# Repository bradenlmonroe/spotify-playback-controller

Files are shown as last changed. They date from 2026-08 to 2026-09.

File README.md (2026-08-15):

The overall goal of the project was to create a better way to control my Spotify listening experience.

Music plays a large part in my life, and I rely on having music in the background to get work done.  However, many of the applications I use on the desktop have the same issue - if i want to interact with the app in any way,  to skip the current song, to look at the artist, to even pause it, requires tabbing through all of my screens and getting lost in pages.  If I leave the window open, I lose valuable monitor real estate.

I then set out to find a solution that would allow me to control my music without dedicating a whole monitor to the application.  Although other solutions exist, including modding a depreciated Spotify Car Thing, I concluded that these solutions were outside the scope of what I wanted the project to accomplish.

After going back and forth between a few options, I settled on using an ESP32 as the microcontroller.  I didn't need anything as powerful as a Raspberry Pi 4 or the STM32, and the ESP offered easily plug-and-play operation with the already-required type-C cable connection.

The rotary encoder was a leftover piece from another project, and has added integrations including the push-button capability and the LED embedded in the handle.

The monitor was selected for its size and cost. Additionally, it boasted not supporting touchscreen, which is a benefit for this project due to the rotary encoder being the main source of control.

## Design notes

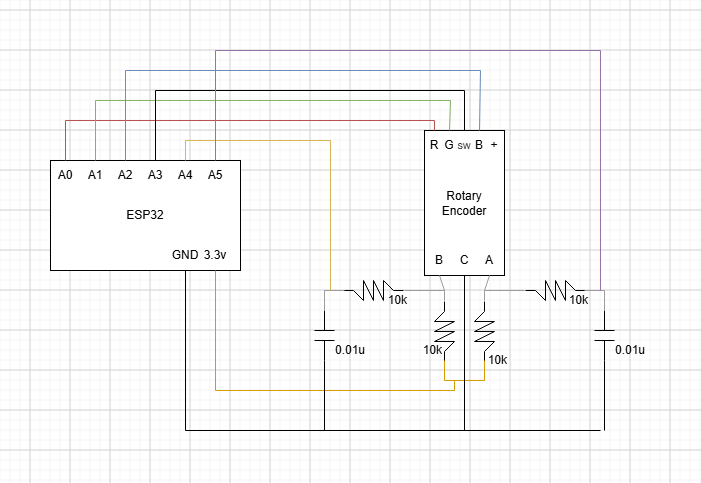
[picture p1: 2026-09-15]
Documentation/spotify desk thing (rotary encoder)-electrical diagram.drawio.png

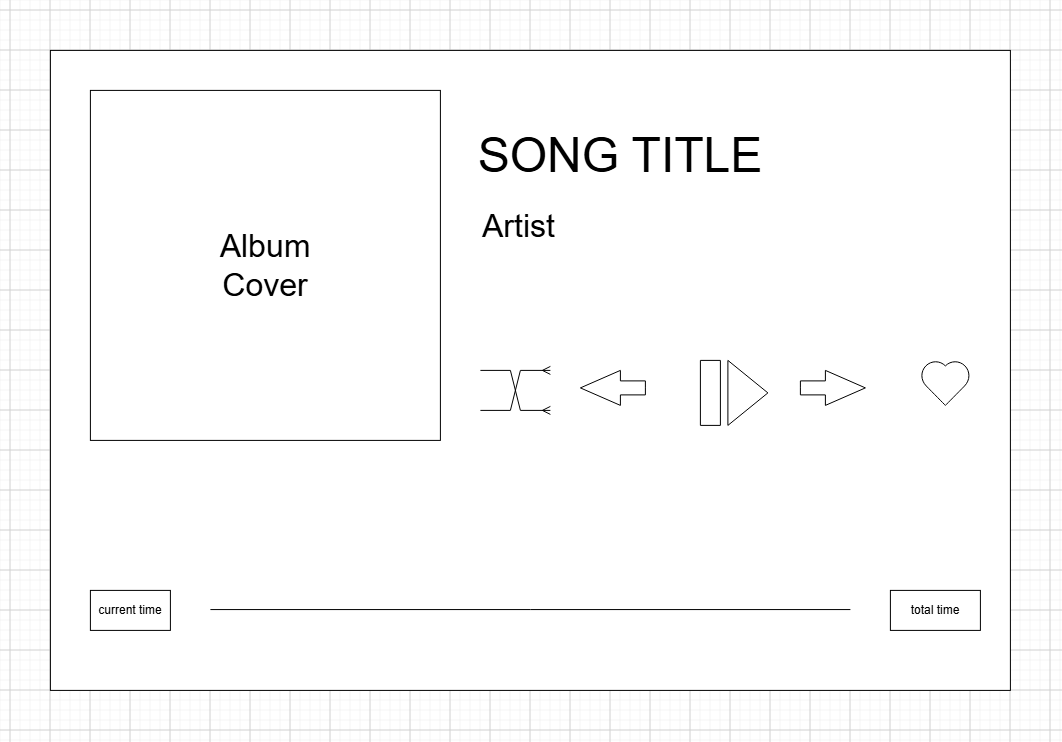
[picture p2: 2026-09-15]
Documentation/spotify desk thing (rotary encoder)-UI.drawio.png

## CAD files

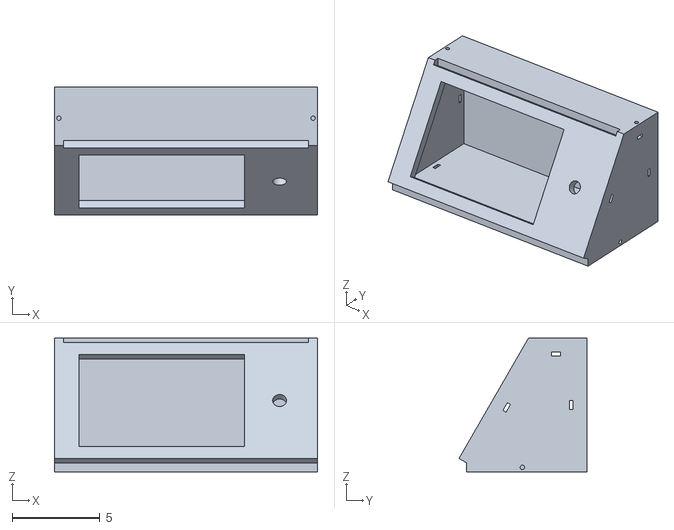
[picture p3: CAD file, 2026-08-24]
hardware/cad/case assembly (1).stl
15.0 x 7.30 x 7.62

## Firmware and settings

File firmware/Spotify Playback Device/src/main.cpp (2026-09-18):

#include <Arduino.h>
#include <SPI.h>
#include <Arduino_GFX_Library.h>
#include <WiFi.h>
#include <WiFiClientSecure.h>
#include <HTTPClient.h>
#include <ArduinoJson.h>
#include <JPEGDEC.h>
#include "esp_heap_caps.h"
#include "secrets.h"

// Known-good wiring from screen_tester.cpp
#define TFT_CS    4
#define TFT_RST   5
#define TFT_DC    6
#define TFT_MOSI  7
#define TFT_SCK   8

// Rotary encoder wiring
#define ENCODER_A    16
#define ENCODER_B    17
#define ENCODER_PUSH 39

Arduino_DataBus *bus =
    new Arduino_HWSPI(TFT_DC, TFT_CS);

Arduino_GFX *gfx =
    new Arduino_ST7796(
        bus,
        TFT_RST,
        1,      // landscape
        false
    );

// ---------- Playback state ----------

struct PlaybackState {
    String title;
    String artist;
    uint32_t durationMs;
    uint32_t progressMs;
    bool playing;
    bool shuffle;
    bool liked;
    String uri;
    String albumArtUrl;
};

PlaybackState playback = {
    "SONG TITLE",
    "Artist",
    222000,     // 3:42
    84000,      // 1:24
    true,
    false,
    false,
    "",
    ""
};

uint32_t positionReceivedAt = 0;

// ---------- Spotify / network state ----------

String spotifyAccessToken;
uint32_t spotifyTokenExpiresAt = 0;
uint32_t lastSpotifyPoll = 0;
uint32_t spotifyRefreshRequestedAt = 0;

constexpr uint32_t SPOTIFY_POLL_INTERVAL = 2000;
constexpr uint32_t SPOTIFY_COMMAND_REFRESH_DELAY = 350;

bool albumArtNeedsUpdate = false;
volatile bool albumArtTaskRunning = false;

constexpr size_t ALBUM_URL_SIZE = 256;
char pendingAlbumArtUrl[ALBUM_URL_SIZE] = "";


// ---------- 480 x 320 layout ----------

constexpr int ALBUM_X = 20;
constexpr int ALBUM_Y = 25;
constexpr int ALBUM_SIZE = 190;

constexpr int INFO_X = 230;

constexpr int BAR_X = 65;
constexpr int BAR_Y = 285;
constexpr int BAR_W = 350;
constexpr int BAR_H = 4;

// ---------- Encoder / control selection ----------

enum ControlIndex {
    CONTROL_SHUFFLE = 0,
    CONTROL_PREVIOUS,
    CONTROL_PLAY_PAUSE,
    CONTROL_NEXT,
    CONTROL_LIKE,
    CONTROL_COUNT
};

int selectedControl = CONTROL_PLAY_PAUSE;

// Set this to -1 if the knob moves opposite the direction you expect.
constexpr int ENCODER_DIRECTION = 1;

int8_t encoderAccumulator = 0;
uint8_t previousEncoderState = 0;

// The SparkFun encoder button is unusual: SW idles LOW and goes HIGH
// when pressed, so use INPUT_PULLDOWN + a RISING-edge interrupt.
volatile bool buttonFlagPressed = false;
volatile uint32_t lastButtonISRTime = 0;
constexpr uint32_t BUTTON_DEBOUNCE_MS = 30;

void IRAM_ATTR buttonISR()
{
    uint32_t now = millis();

    if (now - lastButtonISRTime > BUTTON_DEBOUNCE_MS) {
        buttonFlagPressed = true;
        lastButtonISRTime = now;
    }
}

void drawAlbumPlaceholder();
void drawSongInfo();
void drawControls();
void resetProgressBar();
bool downloadAndDrawAlbumArt(const String &url);
void updateAlbumArt();
void albumArtTask(void *parameter);

// ---------- WiFi / Spotify ----------

void connectWiFi()
{
    Serial.print("Connecting to WiFi");

    WiFi.mode(WIFI_STA);
    WiFi.begin(WIFI_SSID, WIFI_PASSWORD);

    while (WiFi.status() != WL_CONNECTED) {
        delay(500);
        Serial.print(".");
    }

    Serial.println();
    Serial.println("WiFi connected");
    Serial.print("IP: ");
    Serial.println(WiFi.localIP());
}

bool refreshSpotifyToken()
{
    WiFiClientSecure client;
    client.setInsecure(); // Bring-up only; use certificate validation for production.

    HTTPClient http;

    if (!http.begin(client, "https://accounts.spotify.com/api/token")) {
        Serial.println("Could not connect to Spotify accounts");
        return false;
    }

    http.addHeader("Content-Type", "application/x-www-form-urlencoded");

    String body =
        "grant_type=refresh_token"
        "&refresh_token=" + String(SPOTIFY_REFRESH_TOKEN) +
        "&client_id=" + String(SPOTIFY_CLIENT_ID);

    int status = http.POST(body);
    String response = http.getString();

    if (status != 200) {
        Serial.printf("Token refresh failed: HTTP %d\n", status);
        Serial.println(response);
        http.end();
        return false;
    }

    JsonDocument doc;
    DeserializationError error = deserializeJson(doc, response);

    if (error) {
        Serial.print("Could not parse token JSON: ");
        Serial.println(error.c_str());
        http.end();
        return false;
    }

    spotifyAccessToken = doc["access_token"].as<String>();
    uint32_t expiresIn = doc["expires_in"] | 3600;

    // Refresh one minute before Spotify's reported expiration.
    spotifyTokenExpiresAt = millis() + (expiresIn > 60 ? expiresIn - 60 : expiresIn) * 1000UL;

    Serial.println("Spotify access token obtained");
    http.end();
    return !spotifyAccessToken.isEmpty();
}

String urlEncode(const String &value)
{
    String encoded;
    const char *hex = "0123456789ABCDEF";

    for (size_t i = 0; i < value.length(); ++i) {
        uint8_t c = (uint8_t)value[i];

        if ((c >= 'a' && c <= 'z') ||
            (c >= 'A' && c <= 'Z') ||
            (c >= '0' && c <= '9') ||
            c == '-' || c == '_' || c == '.' || c == '~') {
            encoded += (char)c;
        } else {
            encoded += '%';
            encoded += hex[(c >> 4) & 0x0F];
            encoded += hex[c & 0x0F];
        }
    }

    return encoded;
}

bool spotifySuccess(int status)
{
    return status >= 200 && status < 300;
}

int spotifyRequest(const char *method, const String &url, String &response,
                   const String &body = "")
{
    if (WiFi.status() != WL_CONNECTED || spotifyAccessToken.isEmpty()) {
        return -1;
    }

    WiFiClientSecure client;
    client.setInsecure();

    HTTPClient http;
    if (!http.begin(client, url)) {
        return -1;
    }

    http.addHeader("Authorization", "Bearer " + spotifyAccessToken);

    int status = -1;

    if (strcmp(method, "GET") == 0) {
        status = http.GET();
    }
    else if (strcmp(method, "POST") == 0) {
        if (body.length()) {
            http.addHeader("Content-Type", "application/json");
            status = http.POST(body);
        }
        else {
            // ESP32 HTTPClient does NOT add Content-Length when size == 0.
            // Spotify expects a body length on these bodyless POST commands.
            http.addHeader("Content-Length", "0");
            status = http.sendRequest("POST");
        }
    }
    else if (strcmp(method, "PUT") == 0) {
        if (body.length()) {
            http.addHeader("Content-Type", "application/json");
            status = http.PUT(body);
        }
        else {
            // Explicitly send Content-Length: 0 for pause/shuffle/etc.
            http.addHeader("Content-Length", "0");
            status = http.sendRequest("PUT");
        }
    }
    else if (strcmp(method, "DELETE") == 0) {
        http.addHeader("Content-Length", "0");
        status = http.sendRequest("DELETE");
    }

    // Avoid trying to drain an unknown-length/bodyless error response.
    // Playback GETs and other JSON responses normally have a positive length.
    if (status > 0 && http.getSize() > 0) {
        response = http.getString();
    }

    http.end();
    return status;
}

int spotifyRequestWithRefresh(const char *method, const String &url,
                              String &response, const String &body = "")
{
    int status = spotifyRequest(method, url, response, body);

    if (status == 401 && refreshSpotifyToken()) {
        response = "";
        status = spotifyRequest(method, url, response, body);
    }

    return status;
}

void requestSpotifyStateRefresh()
{
    spotifyRefreshRequestedAt = millis();
}

bool spotifyNext()
{
    String response;
    int status = spotifyRequestWithRefresh(
        "POST", "https://api.spotify.com/v1/me/player/next", response);

    Serial.printf("Next: HTTP %d\n", status);
    if (spotifySuccess(status)) requestSpotifyStateRefresh();
    return spotifySuccess(status);
}

bool spotifyPrevious()
{
    String response;
    int status = spotifyRequestWithRefresh(
        "POST", "https://api.spotify.com/v1/me/player/previous", response);

    Serial.printf("Previous: HTTP %d\n", status);
    if (spotifySuccess(status)) requestSpotifyStateRefresh();
    return spotifySuccess(status);
}

bool spotifyPause()
{
    String response;
    int status = spotifyRequestWithRefresh(
        "PUT", "https://api.spotify.com/v1/me/player/pause", response);

    Serial.printf("Pause: HTTP %d\n", status);
    if (spotifySuccess(status)) requestSpotifyStateRefresh();
    return spotifySuccess(status);
}

bool spotifyPlay()
{
    String response;
    int status = spotifyRequestWithRefresh(
        "PUT",
        "https://api.spotify.com/v1/me/player/play",
        response,
        "{}"
    );

    Serial.printf("Play: HTTP %d\n", status);
    if (spotifySuccess(status)) requestSpotifyStateRefresh();
    return spotifySuccess(status);
}

bool spotifySetShuffle(bool enabled)
{
    String response;
    String url = "https://api.spotify.com/v1/me/player/shuffle?state=";
    url += enabled ? "true" : "false";

    int status = spotifyRequestWithRefresh("PUT", url, response);
    Serial.printf("Shuffle: HTTP %d\n", status);

    if (spotifySuccess(status)) requestSpotifyStateRefresh();
    return spotifySuccess(status);
}

bool spotifyCheckLiked(const String &uri, bool &liked)
{
    if (uri.isEmpty()) return false;

    String response;
    String url = "https://api.spotify.com/v1/me/library/contains?uris=" +
                 urlEncode(uri);

    int status = spotifyRequestWithRefresh("GET", url, response);

    if (status != 200) {
        Serial.printf("Liked-state check: HTTP %d\n", status);
        return false;
    }

    JsonDocument doc;
    if (deserializeJson(doc, response)) {
        return false;
    }

    liked = doc[0] | false;
    return true;
}

bool spotifySetLiked(bool liked)
{
    if (playback.uri.isEmpty()) {
        Serial.println("No Spotify URI available for current item");
        return false;
    }

    String response;
    String url = "https://api.spotify.com/v1/me/library?uris=" +
                 urlEncode(playback.uri);

    int status = spotifyRequestWithRefresh(
        liked ? "PUT" : "DELETE", url, response);

    Serial.printf("%s library item: HTTP %d\n",
                  liked ? "Save" : "Remove", status);

    // Current library endpoints return HTTP 200 on success.
    if (status == 200) {
        playback.liked = liked;
        drawControls();
        requestSpotifyStateRefresh();
        return true;
    }

    return false;
}

bool getSpotifyPlayback()
{
    if (spotifyAccessToken.isEmpty()) {
        Serial.println("No Spotify access token");
        return false;
    }

    String response;
    int status = spotifyRequestWithRefresh(
        "GET", "https://api.spotify.com/v1/me/player", response);

    if (status == 204) {
        Serial.println("No active Spotify playback");
        return true;
    }

    if (status != 200) {
        Serial.printf("Playback request failed: HTTP %d\n", status);
        if (!response.isEmpty()) Serial.println(response);
        return false;
    }

    JsonDocument doc;
    DeserializationError error = deserializeJson(doc, response);

    if (error) {
        Serial.print("Could not parse playback JSON: ");
        Serial.println(error.c_str());
        return false;
    }

    JsonObject item = doc["item"].as<JsonObject>();
    if (item.isNull()) {
        Serial.println("Spotify returned no current item");
        return true;
    }

    String newTitle = item["name"].as<String>();
    String newArtist = item["artists"][0]["name"].isNull()
                           ? ""
                           : item["artists"][0]["name"].as<String>();
    String newUri = item["uri"].isNull() ? "" : item["uri"].as<String>();

    // Spotify returns album artwork in several sizes, widest first.
    // Choose the smallest image that is still at least as large as our
    // album-art box. This avoids downloading the 640x640 image unnecessarily.
    String newAlbumArtUrl = "";
    int bestAlbumWidth = 1000000;

    JsonArray images = item["album"]["images"].as<JsonArray>();
    for (JsonObject image : images) {
        int width = image["width"] | 0;
        String url = image["url"].as<String>();

        if (!url.isEmpty() && width >= ALBUM_SIZE && width < bestAlbumWidth) {
            bestAlbumWidth = width;
            newAlbumArtUrl = url;
        }
    }

    // Fallback to the first image if Spotify did not provide dimensions.
    if (newAlbumArtUrl.isEmpty() && images.size() > 0) {
        newAlbumArtUrl = images[0]["url"].as<String>();
    }

    uint32_t newDuration = item["duration_ms"] | 0;
    uint32_t newProgress = doc["progress_ms"] | 0;
    bool newPlaying = doc["is_playing"] | false;
    bool newShuffle = doc["shuffle_state"] | false;

    bool songChanged = (newUri != playback.uri);
    bool controlsChanged =
        (newPlaying != playback.playing) ||
        (newShuffle != playback.shuffle);

    playback.title = newTitle;
    playback.artist = newArtist;
    playback.durationMs = newDuration;
    playback.progressMs = newProgress;
    playback.playing = newPlaying;
    playback.shuffle = newShuffle;
    playback.uri = newUri;
    playback.albumArtUrl = newAlbumArtUrl;
    positionReceivedAt = millis();

    if (songChanged) {
        bool newLiked = false;
        if (spotifyCheckLiked(playback.uri, newLiked)) {
            if (newLiked != playback.liked) controlsChanged = true;
            playback.liked = newLiked;
        } else {
            playback.liked = false;
        }

        drawSongInfo();
        resetProgressBar();
        controlsChanged = true;

        // Copy the URL while still on loopTask. The album-art FreeRTOS task
        // never reads playback.albumArtUrl, avoiding cross-task Arduino String access.
        strncpy(
            pendingAlbumArtUrl,
            playback.albumArtUrl.c_str(),
            ALBUM_URL_SIZE - 1
        );
        pendingAlbumArtUrl[ALBUM_URL_SIZE - 1] = '\0';

        albumArtNeedsUpdate = true;
    }

    if (controlsChanged) {
        drawControls();
    }

    Serial.printf("Spotify: %s - %s [%s]\n",
                  playback.artist.c_str(),
                  playback.title.c_str(),
                  playback.playing ? "playing" : "paused");

    return true;
}

void updateSpotify()
{
    uint32_t now = millis();

    if (spotifyTokenExpiresAt != 0 &&
        (int32_t)(now - spotifyTokenExpiresAt) >= 0) {
        refreshSpotifyToken();
    }

    bool commandRefreshDue =
        spotifyRefreshRequestedAt != 0 &&
        now - spotifyRefreshRequestedAt >= SPOTIFY_COMMAND_REFRESH_DELAY;

    bool periodicRefreshDue =
        now - lastSpotifyPoll >= SPOTIFY_POLL_INTERVAL;

    if (!commandRefreshDue && !periodicRefreshDue) {
        return;
    }

    spotifyRefreshRequestedAt = 0;
    lastSpotifyPoll = now;
    getSpotifyPlayback();
}

// ---------- Helpers ----------

String formatTime(uint32_t ms)
{
    uint32_t seconds = ms / 1000;
    uint32_t minutes = seconds / 60;
    seconds %= 60;

    char buffer[12];
    snprintf(buffer, sizeof(buffer), "%lu:%02lu",
             (unsigned long)minutes,
             (unsigned long)seconds);

    return String(buffer);
}

uint32_t getCurrentPosition()
{
    if (!playback.playing) {
        return playback.progressMs;
    }

    uint32_t position =
        playback.progressMs + (millis() - positionReceivedAt);

    if (position > playback.durationMs) {
        position = playback.durationMs;
    }

    return position;
}

// ---------- Album art ----------

// JPEGDEC sends decoded RGB565 blocks through this callback.
static int drawAlbumJpegBlock(JPEGDRAW *pDraw)
{
    int x = pDraw->x;
    int y = pDraw->y;
    int w = pDraw->iWidth;
    int h = pDraw->iHeight;

    // The decode origin is chosen so all decoded blocks should stay inside
    // the 190x190 album-art region. Abort the decode if a block would escape.
    if (x < ALBUM_X || y < ALBUM_Y ||
        x + w > ALBUM_X + ALBUM_SIZE ||
        y + h > ALBUM_Y + ALBUM_SIZE) {
        Serial.printf(
            "JPEG block out of bounds: x=%d y=%d w=%d h=%d\n",
            x, y, w, h
        );
        return 0;
    }

    gfx->draw16bitRGBBitmap(
        x,
        y,
        pDraw->pPixels,
        w,
        h
    );

    return 1;
}
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
void loop()
{
    // While albumArtTask is alive, it owns both networking and the TFT.
    // Avoid encoder-triggered TFT writes, Spotify TLS requests, and progress
    // drawing from loopTask until the artwork operation is finished.
    if (albumArtTaskRunning) {
        delay(1);
        return;
    }

    updateEncoder();
    updateSpotify();

    static uint32_t lastProgressDraw = 0;

    if (millis() - lastProgressDraw >= 500) {
        lastProgressDraw = millis();
        drawProgressBar();
    }

    // Starts only after updateSpotify() has fully returned.
    updateAlbumArt();
}

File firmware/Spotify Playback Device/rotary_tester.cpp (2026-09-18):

/*
 * ESP32-S3 Rotary Encoder + Button + RGB LED
 * SparkFun rotary encoder breakout (quadrature A/B, push button, RGB LED)
 *
 * Wiring:
 *   Encoder A   -> GPIO 16
 *   Encoder B   -> GPIO 15
 *   Button      -> GPIO 8
 *   LED R       -> GPIO 4
 *   LED G       -> GPIO 5
 *   LED B       -> GPIO 6
 *   VCC         -> 3.3V (through your filtering caps)
 *   GND         -> GND
 *
 * Decoding uses a full quadrature state table (robust against
 * contact bounce / partial detents) rather than naive edge counting.
 */

#include <Arduino.h>

// ---------- Pin definitions ----------
static const uint8_t PIN_ENC_A  = 16;
static const uint8_t PIN_ENC_B  = 17;
static const uint8_t PIN_BUTTON = 39;
static const uint8_t PIN_LED_R  = 42;
static const uint8_t PIN_LED_G  = 40;
static const uint8_t PIN_LED_B  = 41;

// ---------- Quadrature state machine ----------
// States
#define R_START      0x0
#define R_CW_FINAL   0x1
#define R_CW_BEGIN   0x2
#define R_CW_NEXT    0x3
#define R_CCW_BEGIN  0x4
#define R_CCW_FINAL  0x5
#define R_CCW_NEXT   0x6
// Direction flags OR'd into the returned state
#define DIR_CW  0x10
#define DIR_CCW 0x20

static const uint8_t stateTable[7][4] = {
  /* R_START     */ {R_START,    R_CW_BEGIN,  R_CCW_BEGIN, R_START},
  /* R_CW_FINAL  */ {R_CW_NEXT,  R_START,     R_CW_FINAL,  R_START | DIR_CW},
  /* R_CW_BEGIN  */ {R_CW_NEXT,  R_CW_BEGIN,  R_START,     R_START},
  /* R_CW_NEXT   */ {R_CW_NEXT,  R_CW_BEGIN,  R_CW_FINAL,  R_START},
  /* R_CCW_BEGIN */ {R_CCW_NEXT, R_START,     R_CCW_BEGIN, R_START},
  /* R_CCW_FINAL */ {R_CCW_NEXT, R_CCW_FINAL, R_START,     R_START | DIR_CCW},
  /* R_CCW_NEXT  */ {R_CCW_NEXT, R_CCW_FINAL, R_CCW_BEGIN, R_START}
};

volatile uint8_t  encState        = R_START;
volatile int32_t  encoderPosition = 0;
volatile int8_t   encoderDirection = 0; // +1 CW, -1 CCW (last confirmed step)

void IRAM_ATTR encoderISR() {
  uint8_t a = digitalRead(PIN_ENC_A);
  uint8_t b = digitalRead(PIN_ENC_B);
  uint8_t pinState = (b << 1) | a;
  encState = stateTable[encState & 0x0F][pinState];
  uint8_t dir = encState & 0x30;
  if (dir == DIR_CW) {
    encoderPosition++;
    encoderDirection = 1;
  } else if (dir == DIR_CCW) {
    encoderPosition--;
    encoderDirection = -1;
  }
}

// ---------- Button (interrupt + debounce) ----------
// NOTE: on this encoder, SW shares the same internal "+" net as the RGB LED's
// common anode. At rest, SW reads LOW; pressing the button pulls it toward
// whatever voltage is on "+". So we use an internal pulldown and trigger on
// RISING - the opposite of the usual pullup/FALLING button pattern.
volatile bool    buttonFlagPressed = false;
volatile uint32_t lastButtonISRTime = 0;

void IRAM_ATTR buttonISR() {
  uint32_t now = millis();
  if (now - lastButtonISRTime > 30) { // 30ms debounce window
    buttonFlagPressed = true;
    lastButtonISRTime = now;
  }
}

// ---------- RGB LED (LEDC PWM) ----------
// Your toolchain is on Arduino-ESP32 core 2.x, which uses the
// channel-based LEDC API: ledcSetup(channel,...) + ledcAttachPin(pin,channel)
// + ledcWrite(channel,duty). (Core 3.x replaced this with pin-based
// ledcAttach()/ledcWrite(pin,...) — not what's installed here.)
static const uint8_t LEDC_CH_R = 0;
static const uint8_t LEDC_CH_G = 1;
static const uint8_t LEDC_CH_B = 2;

void setupLED() {
  ledcSetup(LEDC_CH_R, 5000, 8); // 5 kHz, 8-bit duty
  ledcSetup(LEDC_CH_G, 5000, 8);
  ledcSetup(LEDC_CH_B, 5000, 8);
  ledcAttachPin(PIN_LED_R, LEDC_CH_R);
  ledcAttachPin(PIN_LED_G, LEDC_CH_G);
  ledcAttachPin(PIN_LED_B, LEDC_CH_B);
}

// This is a common-anode RGB LED (shared "+" pin), so each color pin turns
// that color ON when pulled LOW, not HIGH. setColor() still takes normal
// "brightness" values (0 = off, 255 = full on) - the inversion happens here
// so the rest of the code doesn't have to think about it.
void setColor(uint8_t r, uint8_t g, uint8_t b) {
  ledcWrite(LEDC_CH_R, 255 - r);
  ledcWrite(LEDC_CH_G, 255 - g);
  ledcWrite(LEDC_CH_B, 255 - b);
}

// ---------- Setup ----------
void setup() {
  Serial.begin(115200);
  delay(200);

  // INPUT_PULLUP is harmless even though you already have external
  // pull-ups/filtering on the breakout; it just reinforces the idle-high level.
  pinMode(PIN_ENC_A, INPUT_PULLUP);
  pinMode(PIN_ENC_B, INPUT_PULLUP);
  pinMode(PIN_BUTTON, INPUT_PULLDOWN); // SW idles LOW, goes HIGH when pressed

  attachInterrupt(digitalPinToInterrupt(PIN_ENC_A), encoderISR, CHANGE);
  attachInterrupt(digitalPinToInterrupt(PIN_ENC_B), encoderISR, CHANGE);
  attachInterrupt(digitalPinToInterrupt(PIN_BUTTON), buttonISR, RISING);

  setupLED();
  setColor(0, 0, 40); // dim blue = idle

  Serial.println("Rotary encoder ready.");
}

// ---------- Loop ----------
int32_t lastReportedPosition = 0;

void loop() {
  noInterrupts();
  int32_t pos = encoderPosition;
  int8_t  dir = encoderDirection;
  interrupts();

  if (pos != lastReportedPosition) {
    Serial.printf("Position: %ld  (dir %s)\n", (long)pos, dir > 0 ? "CW" : "CCW");
    lastReportedPosition = pos;

    if (dir > 0) {
      setColor(0, 40, 0);  // green flash for CW
    } else {
      setColor(40, 0, 0);  // red flash for CCW
    }
  }

  if (buttonFlagPressed) {
    buttonFlagPressed = false;
    Serial.println("Button pressed!");
    setColor(40, 40, 40); // white flash
    delay(80);
    setColor(0, 0, 40);   // back to idle
  }
}

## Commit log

2026-08-13 formatted repo
    inserted folders and example.txts to build the file organization to the repo specifications i wanted
2026-08-15 8.15.26 v1
    added electrical diagram for implementation of the rotary encoder controls
2026-08-15 8.15.26 v2
    added quick case sketch i drew up, dimensions should be roughly proper but needs to be tuned when parts arrive.
    [case assembly.stl]
2026-08-24 8.24.26 v1
    Screen arrived, so I updated the dimensions on the case and uploaded the new CAD files to the repo. Still waiting on the ESP to arrive
    [case assembly (1).stl, case assembly.stl]
2026-09-15 9.14.2026 v1
    Updated code to read rotary encoder input. Encoder reads properly, but RGB and button presses are unresponsive
2026-09-15 9.14.2026 v2
    RGB and Button presses react properly now. Rotary encoder controller fully works. Next steps include integrating onto spotify dev pages for full control and the local screen UI.
2026-09-15 9.14.2026 v3
    Attempts to make screen work. Currently is dim and does not properly draw red rectangle. Looking to move files into a shorter directory to avoid folder length limit.
    [main.cpp, rotary_tester.cpp]
2026-09-17 9.17.26 v1
    Attempted to fix screen. Moved repository. Created build log, hoping for better progress context through remainder of project
    [main.cpp]
2026-09-18 9.17.26 v4
    Screen now reacts to encoder controls properly. Working on getting screen and encoder to work with developer api
2026-09-18 9.17.26 v5
    Internet access has been added to the ESP. Details like security keys, wifi passwords, wifi networks are all in a file named secrets.h and put in the gitignore to avoid posting this information publicly.
    Final details include putting the album cover on the display and creating the case.
    [main.cpp]
2026-09-18 9.17.26 v6
    Project completed! Much still to clean up, but at the most rudimentary level it works! Next steps include finishing the enclosure, and future steps for firmware are left in build logs.
